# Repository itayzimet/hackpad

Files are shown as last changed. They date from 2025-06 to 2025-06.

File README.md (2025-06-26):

# hackpad
My own take on the hackpad using QMK as firmware

## Features
* 9 keys
* an EC11 encoder controlling volume (mutes upon press)
* a 128x32 oled display showing the currently playing music
* 16 neopixel leds for backlighting efects
* case consisting of two parts
* some nice drawings by my girlfriend on the silkscreen and on the case
* QMK (maybe I'll add VIA sometime)

## Cad model
the keyboard fits together using 7 M3 screws - 3 for the pcb and 4 for the case itself which comes in two parts.

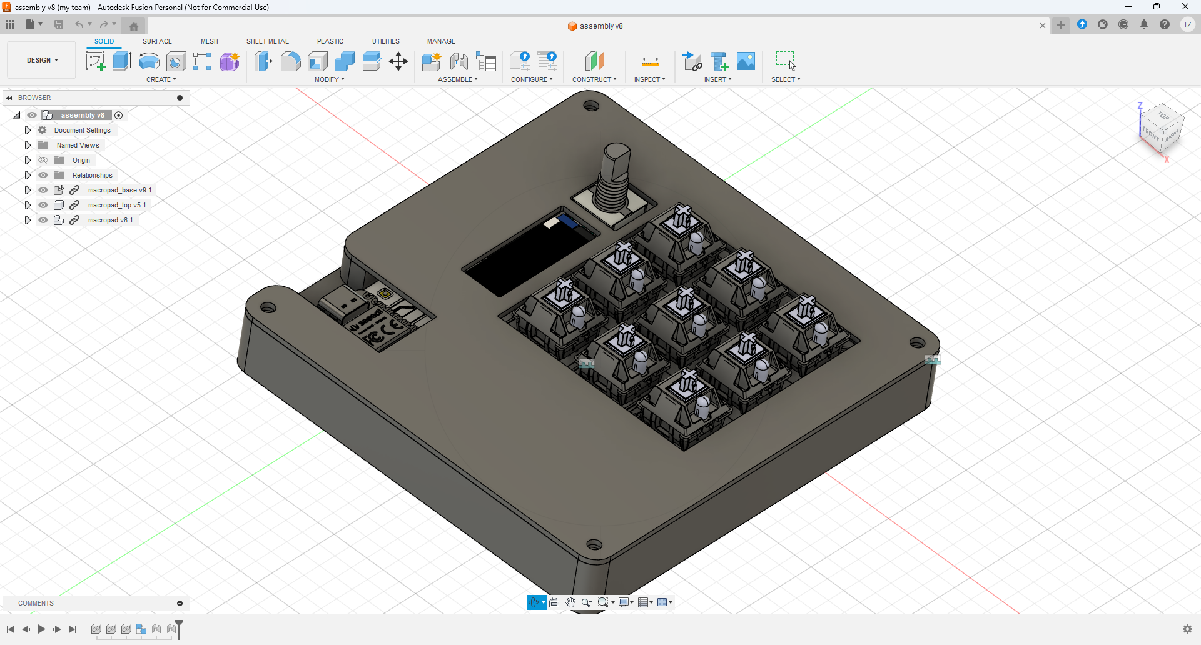
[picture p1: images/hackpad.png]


made in fusion 360 (crashed my computer only 5 times!)

## PCB
My pcb was made in kicad with the silkscreen made up of my girlfriends drawings.

Schematic
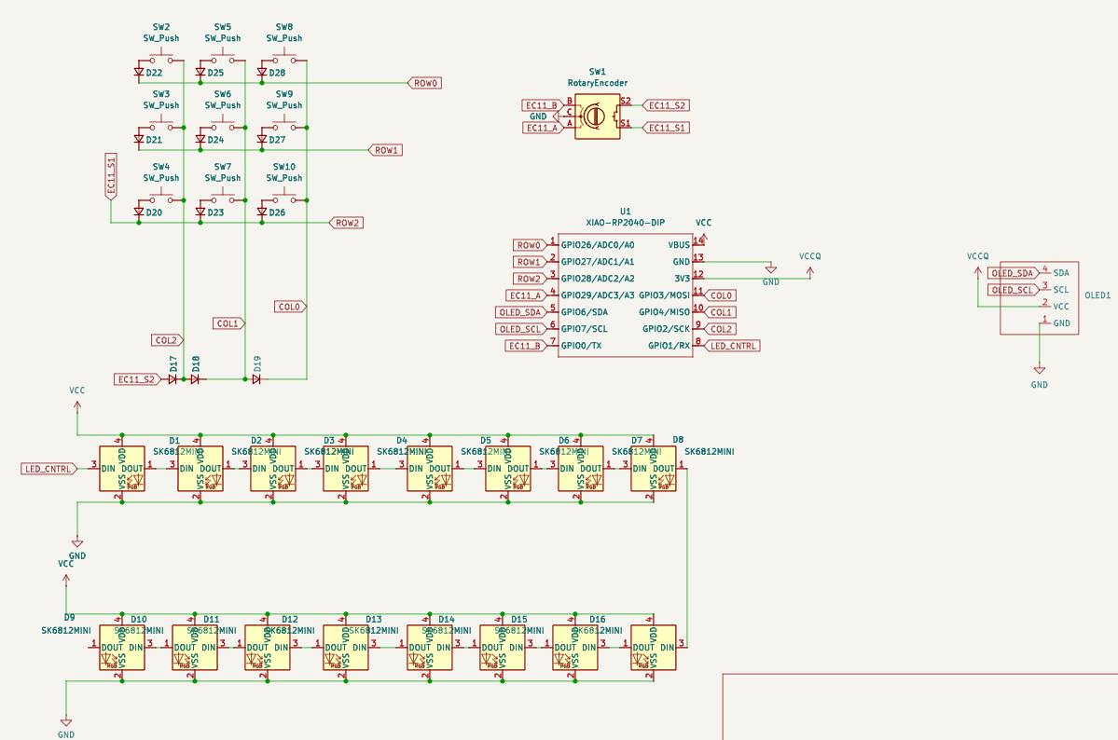
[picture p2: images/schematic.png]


PCB
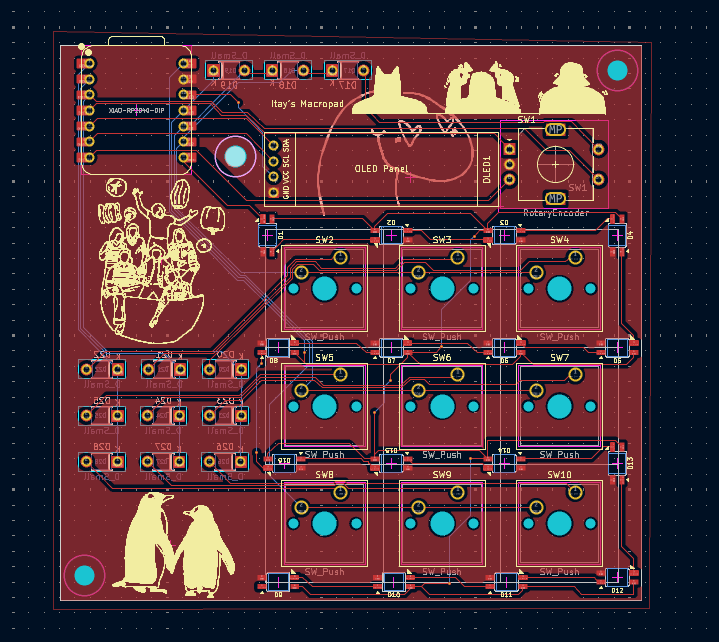
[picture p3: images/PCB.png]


## Firmware and Software
The Firmware is plain QMK but the oled screen is rendered on the host and sent pixel by pixel .
That is because it look nicer and allows support for non-English languages like hebrew.

the screen should look aproximatlly like this:
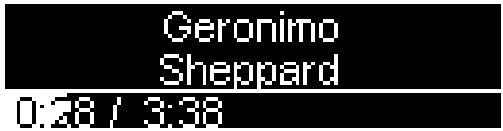
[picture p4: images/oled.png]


claude helped here a little bit but not too much.

for Software install just make sure you have python 3.11 and run:
```bash
pip install numpy maplotlib hidapi pillow winrt-runtime winrt-windows.foudation  winrt-Windows.Media.Control
```
then just run the script found in the "host software" folder and enjoy your music

## BOM:
This should be everything needed for this hackpad:

* 9x Cherry MX switches
* 9x DSA Keycaps
* 7x M3x5x4 Heatset inserts
* 7x M3x4 screws
* 12x 1N4148 DO-35 Diodes
* 16x WS2812B Leds
* 1x 0.91" 128x32 OLED display
* 1x EC11 Rotary encoder
* 1x XIAO seeed RP2040
* 1x pcb
* 1x case (2 3d printed parts)

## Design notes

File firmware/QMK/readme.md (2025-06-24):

# hackpad_itay

![hackpad_itay]

A 9 key macro pad with an oled screen and an encoder

* Keyboard Maintainer: [Itay Asher Zimet](https://github.com/itayzimet)
* Hardware Supported: pcb (ask me)
* Hardware Availability: ask me

Make example for this keyboard (after setting up your build environment):

    make hackpad_itay:default

Flashing example for this keyboard:

    make hackpad_itay:default:flash

See the [build environment setup](https://docs.qmk.fm/#/getting_started_build_tools) and the [make instructions](https://docs.qmk.fm/#/getting_started_make_guide) for more information. Brand new to QMK? Start with our [Complete Newbs Guide](https://docs.qmk.fm/#/newbs).

## Bootloader

Enter the bootloader by pressing the reset button twice while connected to the computer, then just copy the .utf file into the drive that opens:

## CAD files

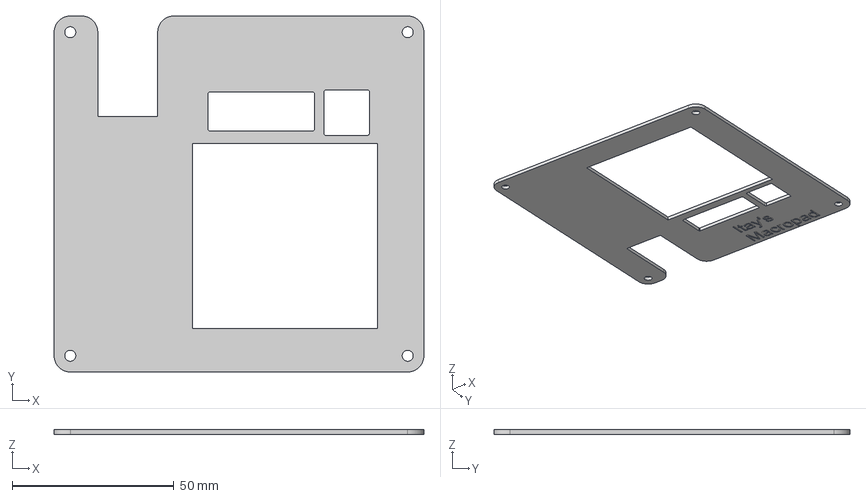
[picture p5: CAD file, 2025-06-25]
production/case/cover.step
114.2 x 110.0 x 1.50 mm

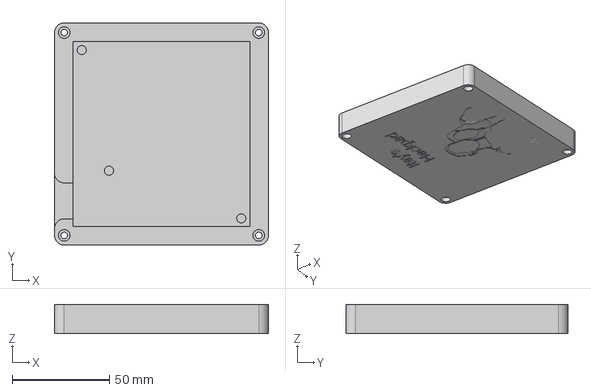
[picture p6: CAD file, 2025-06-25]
production/case/base.step
110.0 x 114.2 x 15.0 mm

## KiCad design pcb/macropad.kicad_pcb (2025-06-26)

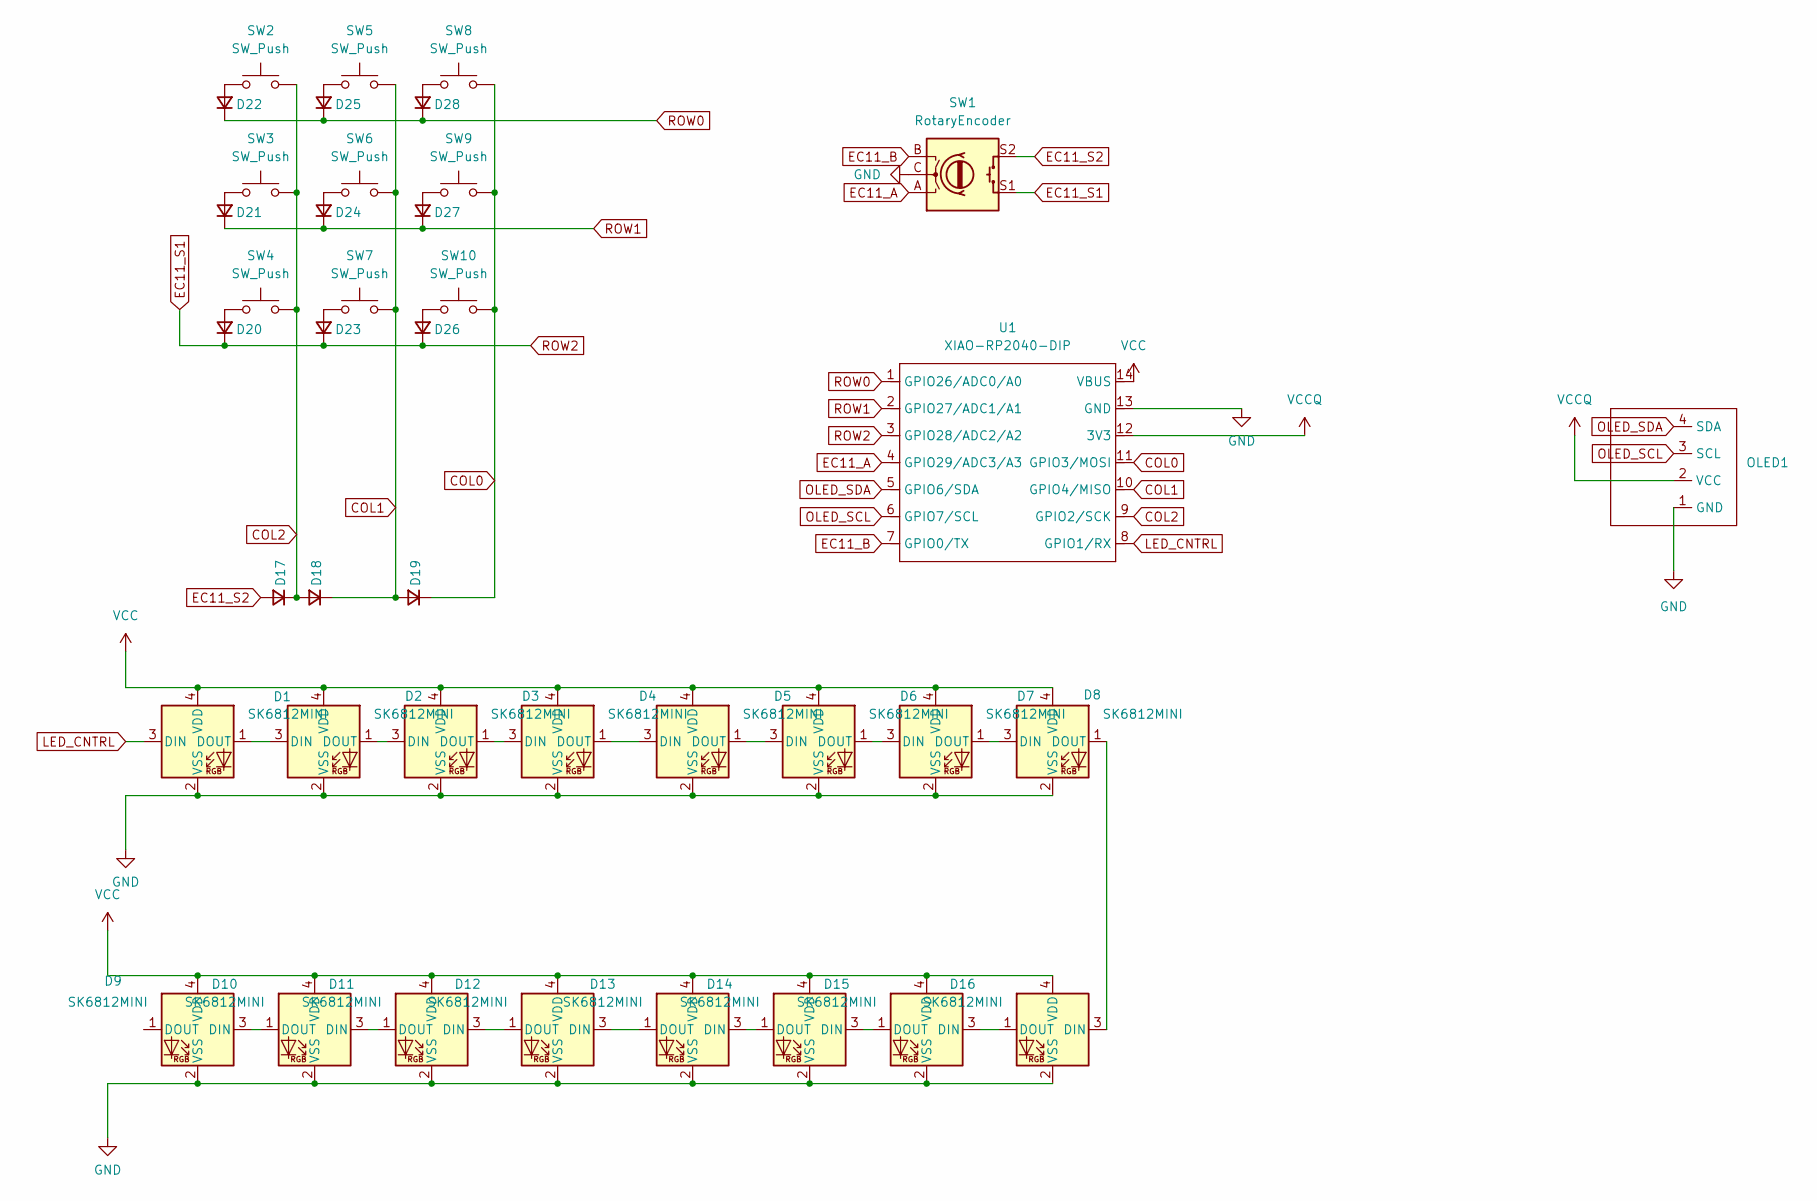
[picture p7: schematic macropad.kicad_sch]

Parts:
D1, D2, D3, D4, D5, D6, D7, D8, D9, D10, D11, D12, D13, D14, D15, D16: SK6812MINI; SK6812-MINI-E
D17, D18, D19, D20, D21, D22, D23, D24, D25, D26, D27, D28: D_Small; D_DO-35_SOD27_P7.62mm_Horizontal
OLED1: SSD1306-0.91-OLED-4pin-128x32
SW1: RotaryEncoder; RotaryEncoder_Alps_EC11E-Switch_Vertical_H20mm
SW2, SW3, SW4, SW5, SW6, SW7, SW8, SW9, SW10: SW_Push; SW_Cherry_MX_1.00u_PCB
U1: XIAO-RP2040-DIP

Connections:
COL0: D19.1 (K), SW8.2, SW9.2, SW10.2, U1.11 (GPIO3/MOSI)
COL1: D18.1 (K), D19.2 (A), SW5.2, SW6.2, SW7.2, U1.10 (GPIO4/MISO)
COL2: D17.1 (K), D18.2 (A), SW2.2, SW3.2, SW4.2, U1.9 (GPIO2/SCK)
EC11_A: SW1.A, U1.4 (GPIO29/ADC3/A3)
EC11_B: SW1.B, U1.7 (GPIO0/TX)
EC11_S1: D20.1 (K), D23.1 (K), D26.1 (K), SW1.S1, U1.3 (GPIO28/ADC2/A2)
EC11_S2: D17.2 (A), SW1.S2
GND: D1.2 (VSS), D2.2 (VSS), D3.2 (VSS), D4.2 (VSS), D5.2 (VSS), D6.2 (VSS), D7.2 (VSS), D8.2 (VSS), D9.2 (VSS), D10.2 (VSS), D11.2 (VSS), D12.2 (VSS), D13.2 (VSS), D14.2 (VSS), D15.2 (VSS), D16.2 (VSS), OLED1.1 (GND), SW1.C, U1.13 (GND)
LED_CNTRL: D1.3 (DIN), U1.8 (GPIO1/RX)
unnamed: D1.1 (DOUT), D2.3 (DIN)
unnamed: D2.1 (DOUT), D3.3 (DIN)
unnamed: D3.1 (DOUT), D4.3 (DIN)
unnamed: D4.1 (DOUT), D5.3 (DIN)
unnamed: D5.1 (DOUT), D6.3 (DIN)
unnamed: D6.1 (DOUT), D7.3 (DIN)
unnamed: D7.1 (DOUT), D8.3 (DIN)
unnamed: D10.3 (DIN), D11.1 (DOUT)
unnamed: D9.3 (DIN), D10.1 (DOUT)
unnamed: D11.3 (DIN), D12.1 (DOUT)
unnamed: D12.3 (DIN), D13.1 (DOUT)
unnamed: D13.3 (DIN), D14.1 (DOUT)
unnamed: D14.3 (DIN), D15.1 (DOUT)
unnamed: D15.3 (DIN), D16.1 (DOUT)
unnamed: D8.1 (DOUT), D16.3 (DIN)
unnamed: D20.2 (A), SW4.1
unnamed: D21.2 (A), SW3.1
unnamed: D22.2 (A), SW2.1
unnamed: D23.2 (A), SW7.1
unnamed: D24.2 (A), SW6.1
unnamed: D25.2 (A), SW5.1
unnamed: D26.2 (A), SW10.1
unnamed: D27.2 (A), SW9.1
unnamed: D28.2 (A), SW8.1
OLED_SCL: OLED1.3 (SCL), U1.6 (GPIO7/SCL)
OLED_SDA: OLED1.4 (SDA), U1.5 (GPIO6/SDA)
ROW0: D22.1 (K), D25.1 (K), D28.1 (K), U1.1 (GPIO26/ADC0/A0)
ROW1: D21.1 (K), D24.1 (K), D27.1 (K), U1.2 (GPIO27/ADC1/A1)
VCC: D1.4 (VDD), D2.4 (VDD), D3.4 (VDD), D4.4 (VDD), D5.4 (VDD), D6.4 (VDD), D7.4 (VDD), D8.4 (VDD), D9.4 (VDD), D10.4 (VDD), D11.4 (VDD), D12.4 (VDD), D13.4 (VDD), D14.4 (VDD), D15.4 (VDD), D16.4 (VDD), U1.14 (VBUS)
VCCQ: OLED1.2 (VCC), U1.12 (3V3)

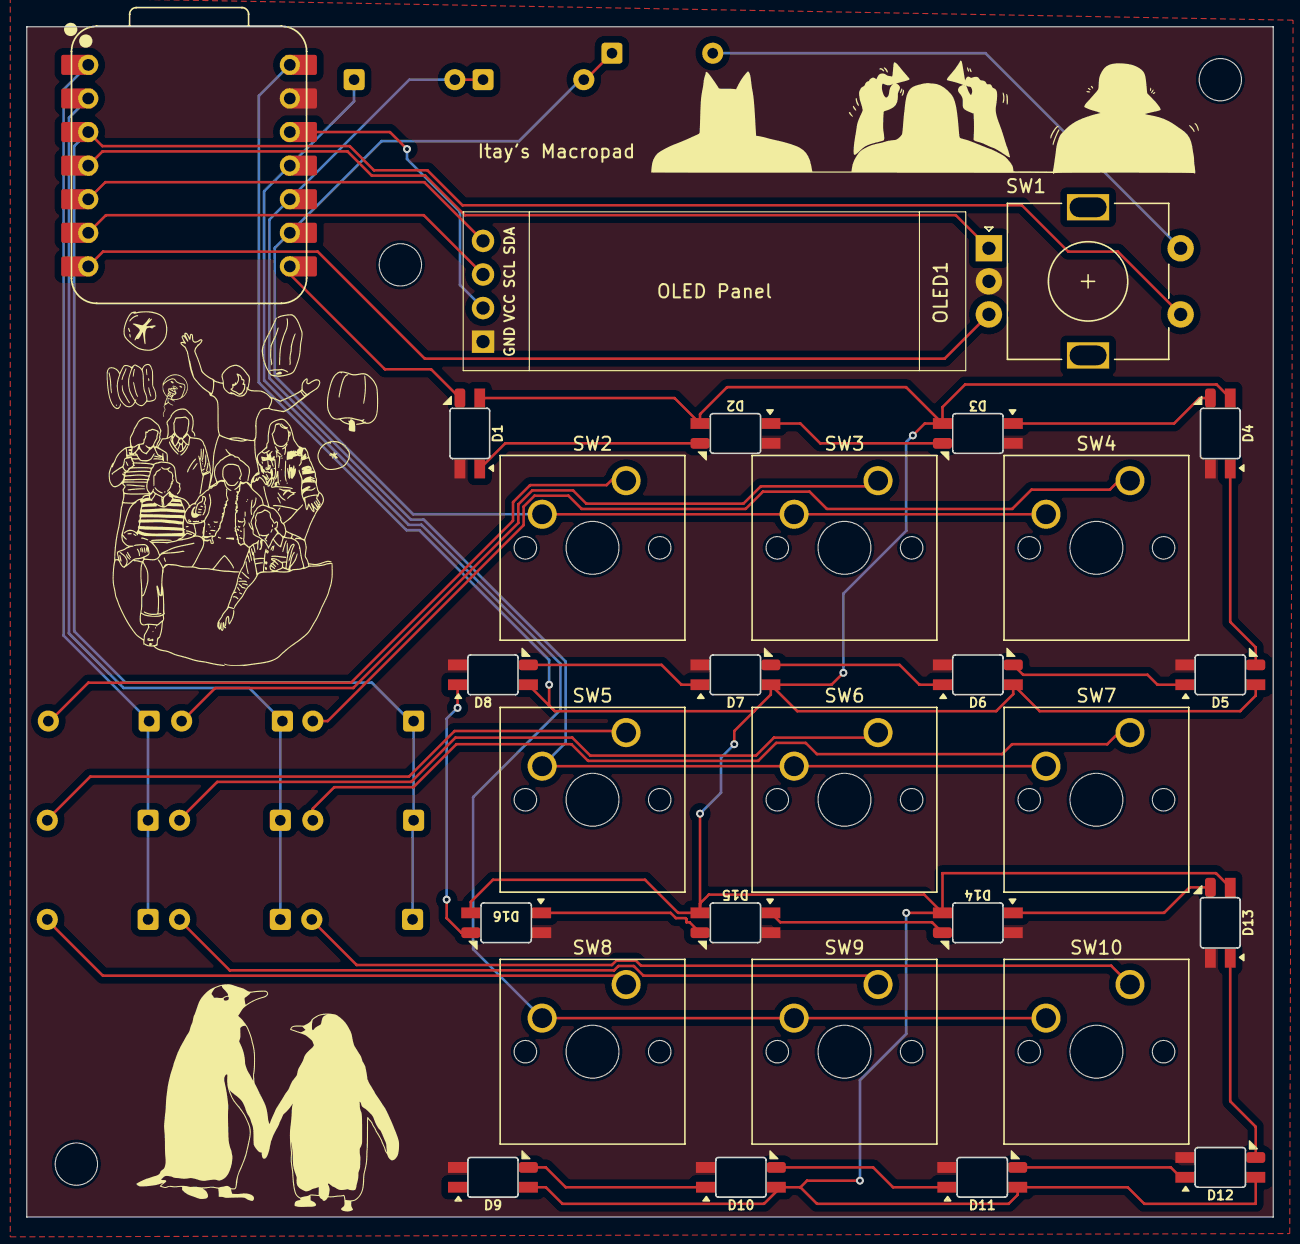
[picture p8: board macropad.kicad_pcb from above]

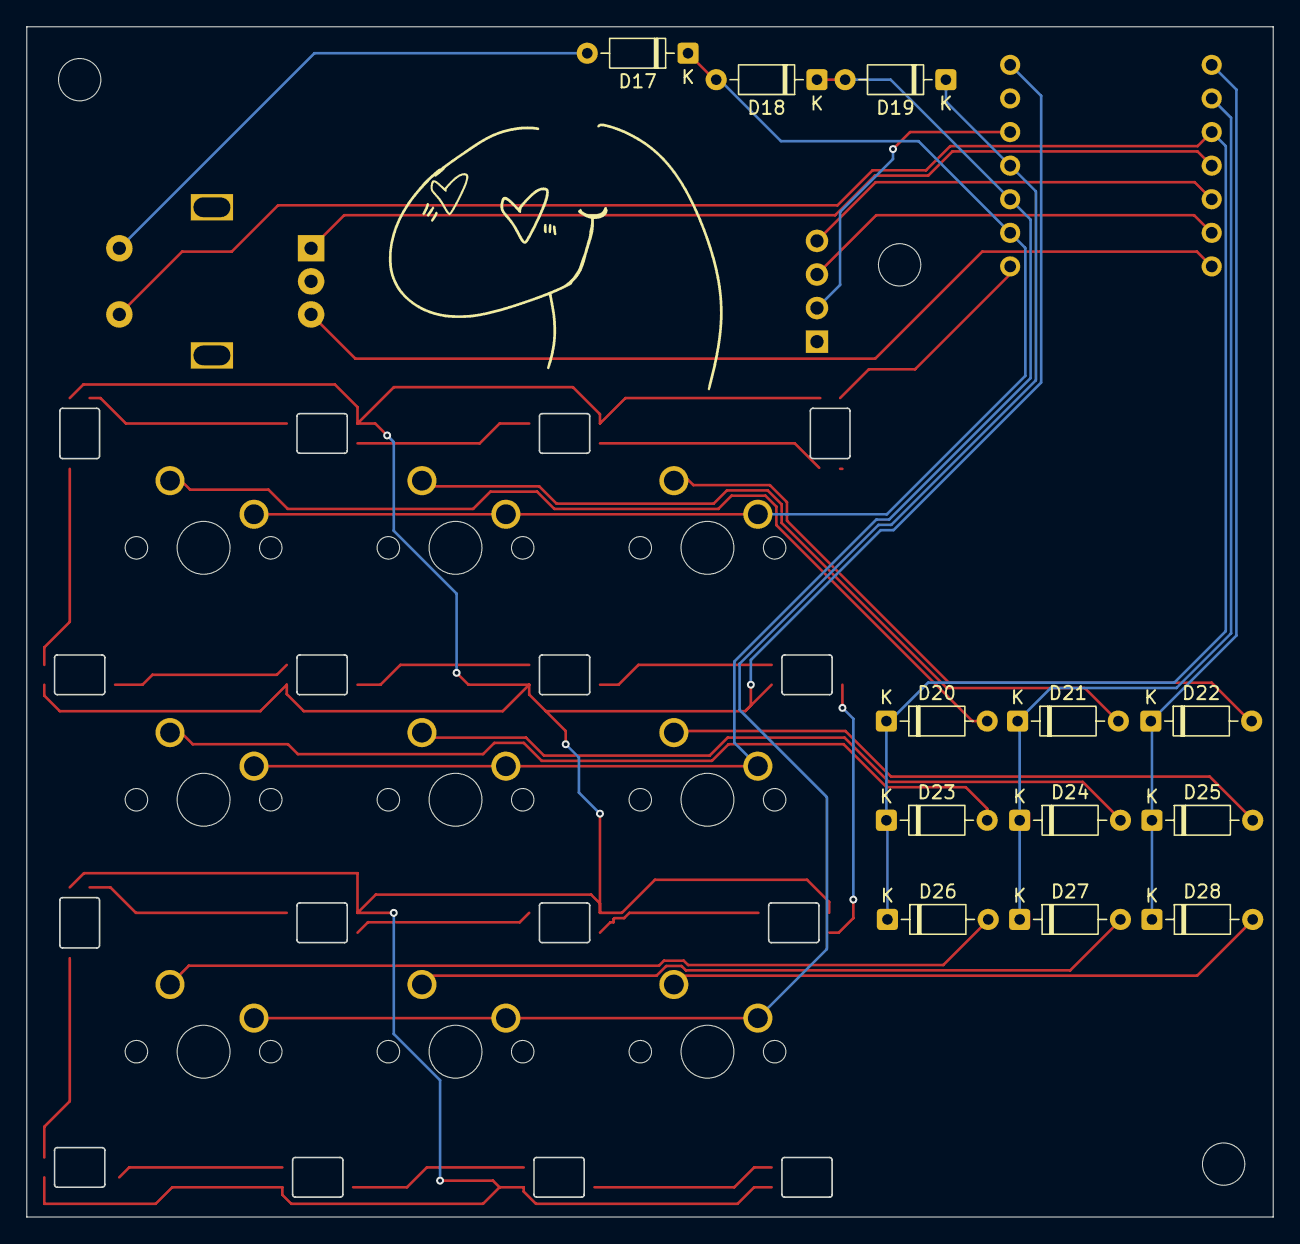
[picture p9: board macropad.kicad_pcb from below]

Board: 2 copper layers, 94.2 x 90.0 mm, 40 parts (12 on the bottom side), 39 nets.

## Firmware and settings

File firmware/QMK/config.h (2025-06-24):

/* Encoder */
#define ENCODER_A_PINS { GP29}
#define ENCODER_B_PINS { GP0}

/* RGB*/
#define WS2812_DI_PIN GP1
#define RGBLIGHT_LED_COUNT 16

/* Oled */
#define OLED_DISPLAY_128X32
#define I2C_DRIVER I2CD1
#define I2C1_SDA_PIN GP6
#define I2C1_SCL_PIN GP7
#define OLED_DISABLE_TIMEOUT

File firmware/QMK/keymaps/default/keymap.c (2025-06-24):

// Copyright 2023 QMK
// SPDX-License-Identifier: GPL-2.0-or-later

#include QMK_KEYBOARD_H

const uint16_t PROGMEM keymaps[][MATRIX_ROWS][MATRIX_COLS] = {
    /*
     * ┌───┬───┬───┐
     * │ 7 │ 8 │ 9 │
     * ├───┼───┼───┤
     * │ 4 │ 5 │ 6 │
     * ├───┼───┼───┤
     * │ 1 │ 2 │ 3 │
     * └───┴───┴───┘
     */
    /* row/col (based on the physical layout of the keypad)
     * ┌───┬───┬───┐
     * │K00│K01│K02│
     * ├───┼───┼───┤
     * │K10│K11│K12│
     * ├───┼───┼───┤
     * │K20│K21│K22│
     * └───┴───┴───┘
     * EC11: click registers as pushing all buttons in row 2 (by pins) or column2 (by geography) - K02, K12, K22
     */
    [0] = LAYOUT(
        KC_MPRV,   KC_MPLY,   KC_MNXT,
        KC_P4,   KC_P5,   KC_P6,
        KC_P1,   KC_P2,   KC_P3
    )
};

const uint16_t PROGMEM encoder_map[][1][2] = {
    [0] = {ENCODER_CCW_CW(KC_VOLU, KC_VOLD)},
};

const uint16_t PROGMEM encoder_map_press[] = {KC_MNXT, KC_P6, KC_P3, COMBO_END};
combo_t key_combos[] = {
    COMBO(encoder_map_press, KC_MUTE)};


#ifdef OLED_ENABLE

#define OLED_BUFFER_SIZE (128 * 32 / 8)  // bytes for full 128x32 bitmap

static uint8_t oled_buffer[OLED_BUFFER_SIZE];
static bool frame_ready = false;

// Called from raw HID with the frame bytes
void raw_hid_receive(uint8_t *data, uint8_t length) {
    if (length == OLED_BUFFER_SIZE) {
        memcpy(oled_buffer, data, OLED_BUFFER_SIZE);
        frame_ready = true;
    } else {
        frame_ready = false;
    }
}

bool oled_task_user(void) {
    if (frame_ready) {
        oled_write_raw((const char*)oled_buffer, OLED_BUFFER_SIZE);
    } else {
        oled_write_ln_P(PSTR("Itay's HackPad\nPlease connect to host and run the host script"), false);
    }
    return false;  // We don't need to redraw the OLED
}

#endif

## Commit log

2025-06-17 initial (v0.00001)
    [macropad.kicad_pcb, macropad.kicad_sch, macropad.step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]
2025-06-19 changes to the pcb, case changes will follow
    [macropad.kicad_pcb, macropad.kicad_sch]
2025-06-22 remade pcb
    removed leds and better wiring (much better)
    [macropad.kicad_pcb, macropad.kicad_sch]
2025-06-22 tidy wiring
    [macropad.kicad_pcb]
2025-06-22 added leds
    [macropad.kicad_pcb, macropad.kicad_sch]
2025-06-23 added the ec11 as a switch and some extra organization
    [macropad-B_Cu.gbl, macropad-B_Cu.gbr, macropad-B_Mask.gbr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]
2025-06-24 organization, firmware and some cleanup
    [base.step, cover.step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]
2025-06-25 added drawings and mounting holes
    [base.step, macropad.kicad_pcb]
2025-06-25 Update cover.step
    sync
    [cover.step]
2025-06-25 added gerbers
    [macropad.kicad_pcb]
2025-06-26 switched to the correct diode footprint
    [macropad.kicad_pcb, macropad.kicad_sch]
